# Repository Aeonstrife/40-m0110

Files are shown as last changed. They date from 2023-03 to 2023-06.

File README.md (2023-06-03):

# 40-m0110 PCB
 
An OpenSource 40% PCB compatible with Ani's 40-m0110 case.  
Made for the Indian Mechanical Keyboard Community. 

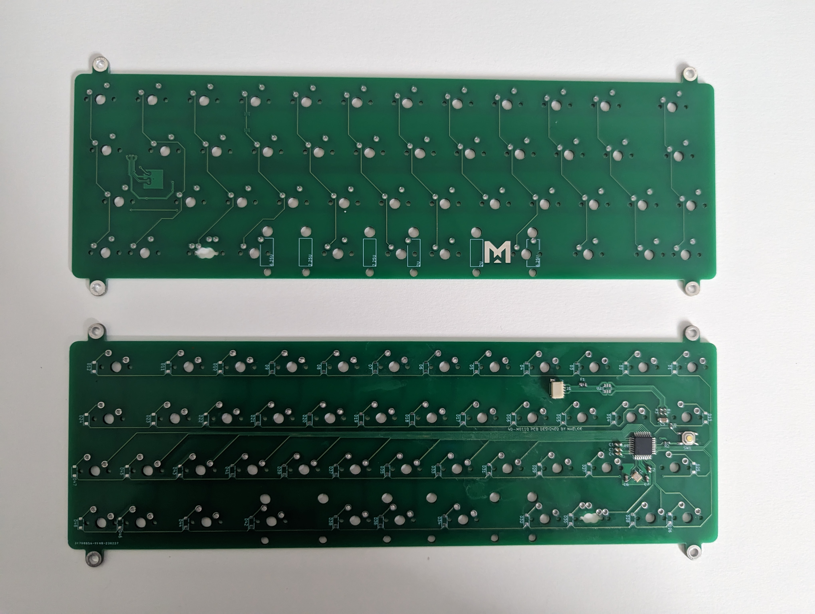
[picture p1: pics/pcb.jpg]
pcb


## Layouts Supported  

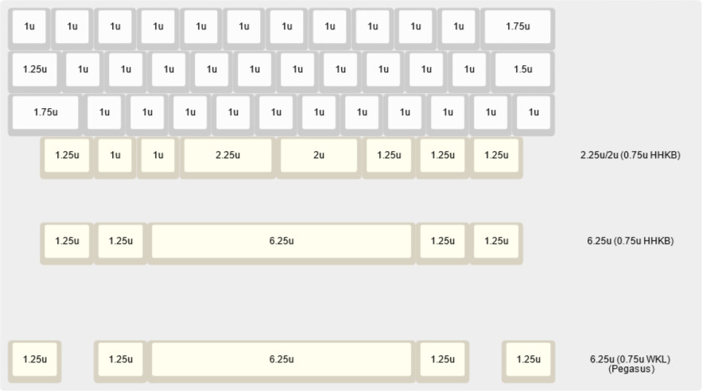
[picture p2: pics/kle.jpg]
layouts supported


## Firmware

### Building the firmware
Copy the folder "40m0110" from the firmware folder to your qmk_firmware/buildakb folder  
Launch QMK MSYS and run: `qmk compile -kb buildakb\40m0110 -km via`  
The firmware file will be created in qmk_firmware/.build folder  

### Flashing the firmware
Launch QMK Toolbox, Select MCU as ATmega32U2, select the firmware file and enable Auto-Flash checkbox.  
Press the reset button on the PCB to put the PCB in Bootloader mode.

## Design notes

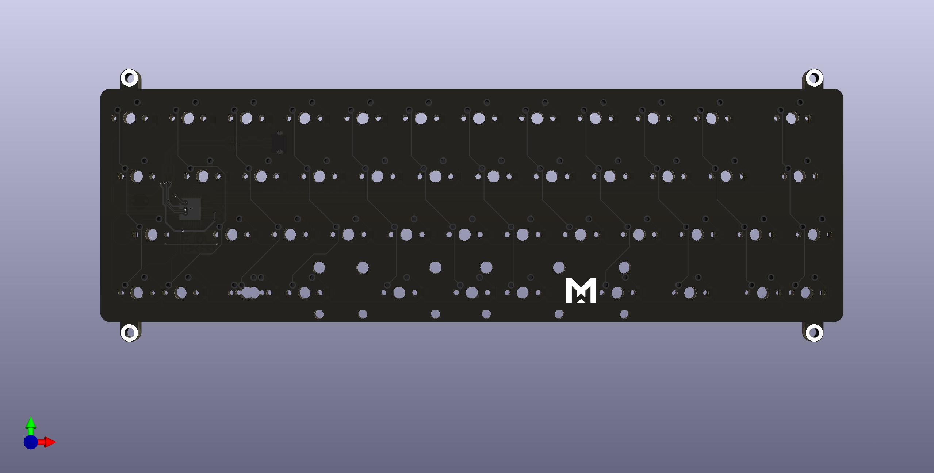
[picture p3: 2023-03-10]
40-m0110.jpg

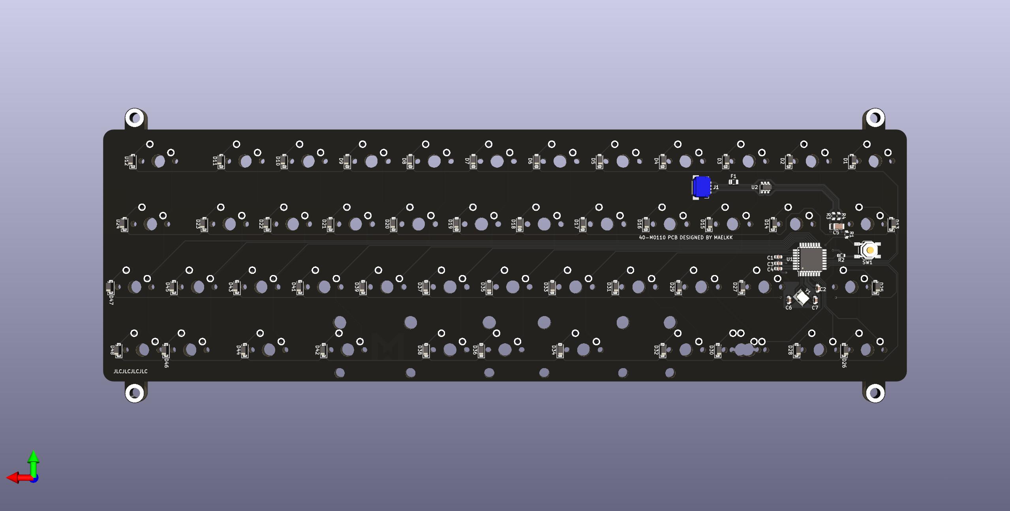
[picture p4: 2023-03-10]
40-m0110_back.jpg

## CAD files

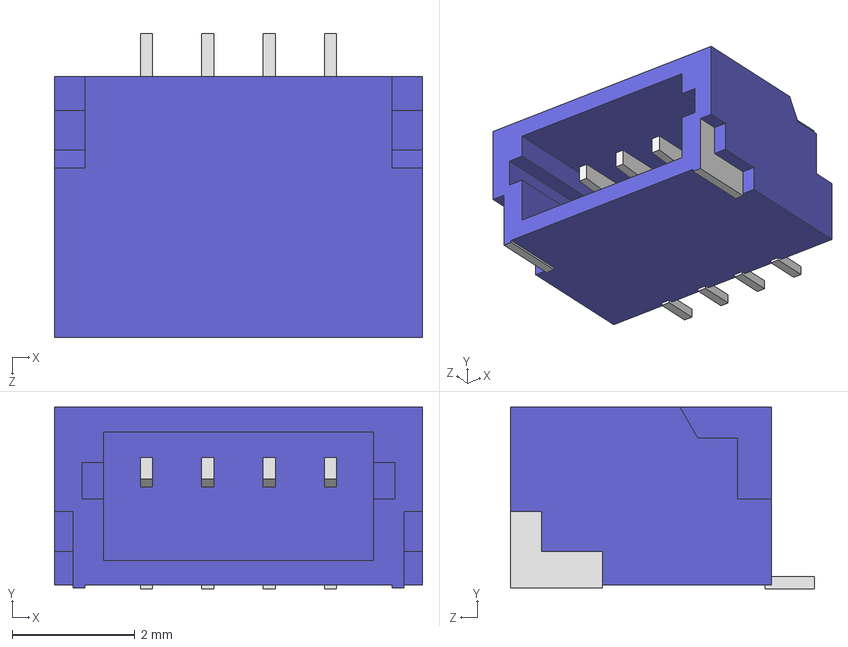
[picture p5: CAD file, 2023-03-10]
SM04B-SRSS-TB.STEP
6.00 x 2.96 x 4.95 mm

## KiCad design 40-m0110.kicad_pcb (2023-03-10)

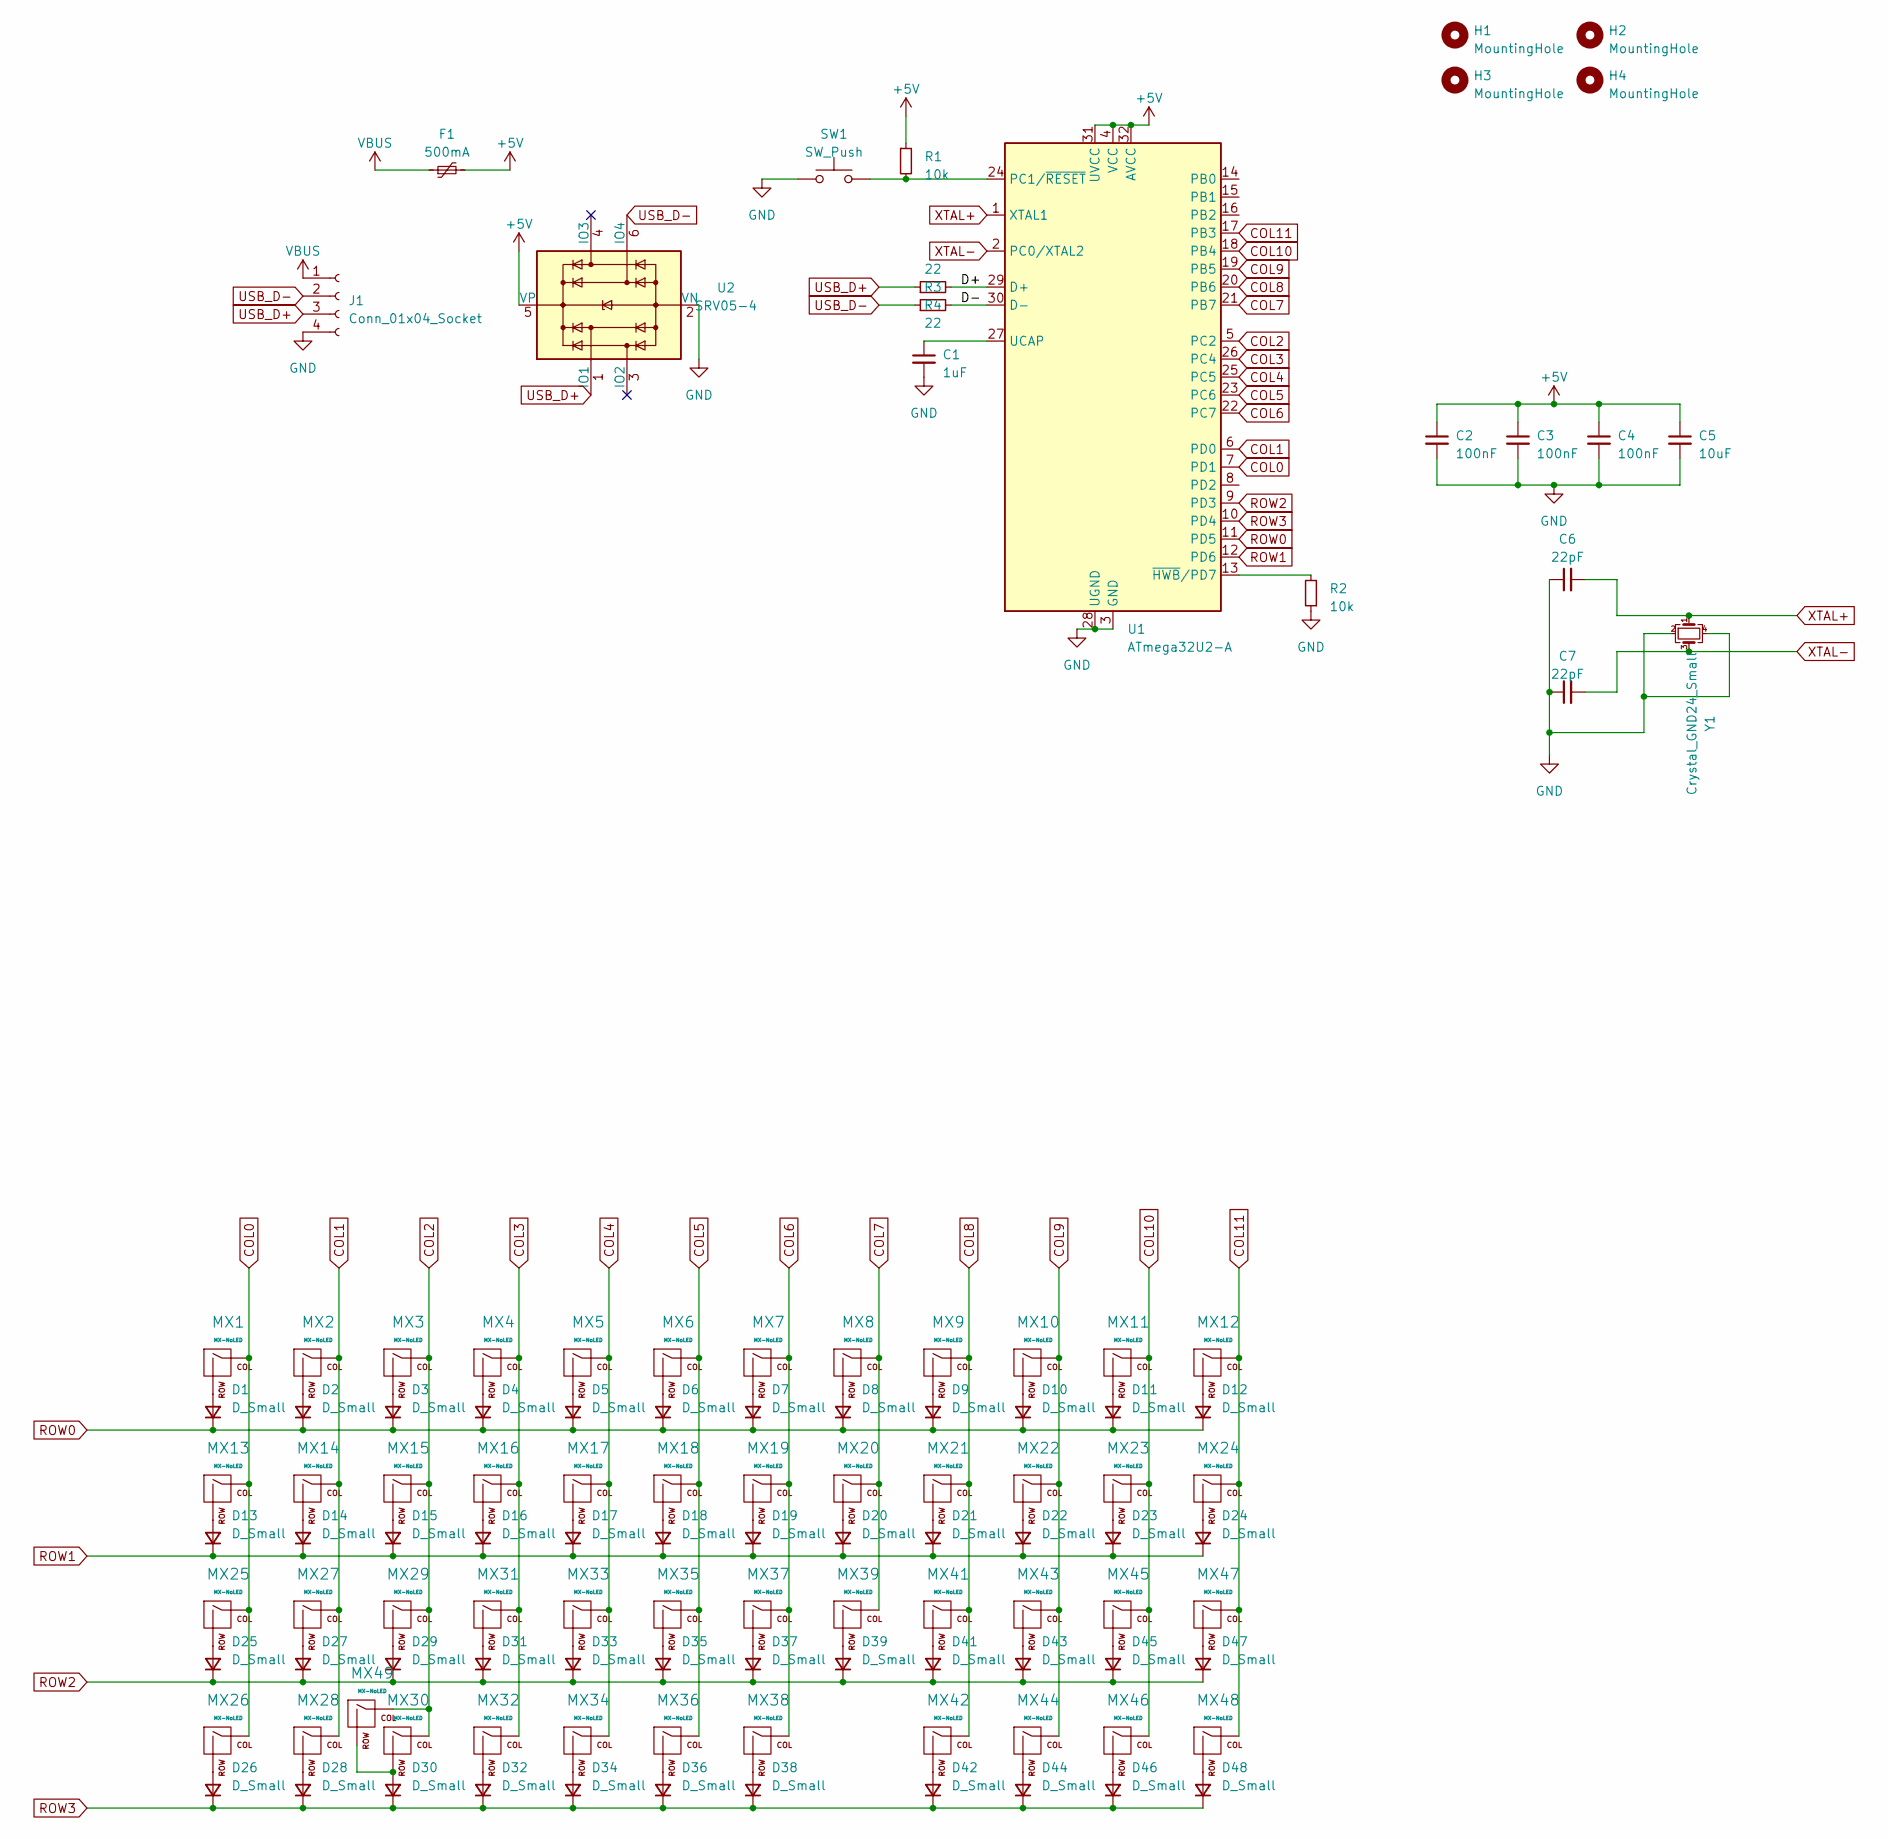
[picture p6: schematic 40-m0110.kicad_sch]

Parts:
C1: 1uF; C_0603_1608Metric
C2, C3, C4: 100nF; C_0603_1608Metric
C5: 10uF; C_0603_1608Metric
C6, C7: 22pF; C_0603_1608Metric
D1, D2, D3, D4, D5, D6, D7, D8, D9, D10, D11, D12, D13, D14, D15, D16, D17, D18, D19, D20, D21, D22, D23, D24, D25, D26, D27, D28, D29, D30, D31, D32, D33, D34, D35, D36, D37, D38, D39, D41, D42, D43, D44, D45, D46, D47, D48: D_Small; D_SOD-123
F1: 500mA; Fuse_0805_2012Metric
H1, H2, H3, H4: MountingHole; MountingHole_3.2mm_M3_DIN965_Pad
J1: Conn_01x04_Socket; SM04B-SRSS-TB(LF)(SN)_mounting-reliefs
MX1, MX2, MX3, MX4, MX5, MX6, MX7, MX8, MX9, MX10, MX11, MX12, MX13, MX14, MX15, MX16, MX17, MX18, MX19, MX20, MX21, MX22, MX23, MX24, MX25, MX26, MX27, MX28, MX29, MX30, MX31, MX32, MX33, MX34, MX35, MX36, MX37, MX38, MX39, MX41, MX42, MX43, MX44, MX45, MX46, MX47, MX48, MX49: MX-NoLED; MXOnly-1U-NoLED
R1, R2: 10k; R_0603_1608Metric
R3, R4: 22; R_0603_1608Metric
SW1: SW_Push; SW_SPST_TL3342
U1: ATmega32U2-A; TQFP-32_7x7mm_P0.8mm
U2: SRV05-4; SOT-23-6
Y1: Crystal_GND24_Small; Crystal_SMD_3225-4Pin_3.2x2.5mm

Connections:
+5V: C2.1, C3.1, C4.1, C5.1, F1.2, R1.1, U1.4 (VCC), U1.31 (UVCC), U1.32 (AVCC), U2.5 (VP)
/D+: R3.2, U1.29 (D+)
/D-: R4.2, U1.30 (D-)
COL0: MX1.1 (COL), MX13.1 (COL), MX25.1 (COL), MX26.1 (COL), U1.7 (PD1)
COL1: MX2.1 (COL), MX14.1 (COL), MX27.1 (COL), MX28.1 (COL), U1.6 (PD0)
COL2: MX3.1 (COL), MX15.1 (COL), MX29.1 (COL), MX30.1 (COL), MX49.1 (COL), U1.5 (PC2)
COL3: MX4.1 (COL), MX16.1 (COL), MX31.1 (COL), MX32.1 (COL), U1.26 (PC4)
COL4: MX5.1 (COL), MX17.1 (COL), MX33.1 (COL), MX34.1 (COL), U1.25 (PC5)
COL5: MX6.1 (COL), MX18.1 (COL), MX35.1 (COL), MX36.1 (COL), U1.23 (PC6)
COL6: MX7.1 (COL), MX19.1 (COL), MX37.1 (COL), MX38.1 (COL), U1.22 (PC7)
COL7: MX8.1 (COL), MX20.1 (COL), MX39.1 (COL), U1.21 (PB7)
COL8: MX9.1 (COL), MX21.1 (COL), MX41.1 (COL), MX42.1 (COL), U1.20 (PB6)
COL9: MX10.1 (COL), MX22.1 (COL), MX43.1 (COL), MX44.1 (COL), U1.19 (PB5)
COL10: MX11.1 (COL), MX23.1 (COL), MX45.1 (COL), MX46.1 (COL), U1.18 (PB4)
COL11: MX12.1 (COL), MX24.1 (COL), MX47.1 (COL), MX48.1 (COL), U1.17 (PB3)
GND: C1.2, C2.2, C3.2, C4.2, C5.2, C6.1, C7.1, J1.4, R2.1, SW1.1, U1.3 (GND), U1.28 (UGND), U2.2 (VN), Y1.2, Y1.4
unnamed: D1.2 (A), MX1.2 (ROW)
unnamed: D2.2 (A), MX2.2 (ROW)
unnamed: D3.2 (A), MX3.2 (ROW)
unnamed: D4.2 (A), MX4.2 (ROW)
unnamed: D5.2 (A), MX5.2 (ROW)
unnamed: D6.2 (A), MX6.2 (ROW)
unnamed: D7.2 (A), MX7.2 (ROW)
unnamed: D8.2 (A), MX8.2 (ROW)
unnamed: D9.2 (A), MX9.2 (ROW)
unnamed: D10.2 (A), MX10.2 (ROW)
unnamed: D11.2 (A), MX11.2 (ROW)
unnamed: D12.2 (A), MX12.2 (ROW)
unnamed: D13.2 (A), MX13.2 (ROW)
unnamed: D14.2 (A), MX14.2 (ROW)
unnamed: D15.2 (A), MX15.2 (ROW)
unnamed: D16.2 (A), MX16.2 (ROW)
unnamed: D17.2 (A), MX17.2 (ROW)
unnamed: D18.2 (A), MX18.2 (ROW)
unnamed: D19.2 (A), MX19.2 (ROW)
unnamed: D20.2 (A), MX20.2 (ROW)
unnamed: D21.2 (A), MX21.2 (ROW)
unnamed: D22.2 (A), MX22.2 (ROW)
unnamed: D23.2 (A), MX23.2 (ROW)
unnamed: D24.2 (A), MX24.2 (ROW)
unnamed: D25.2 (A), MX25.2 (ROW)
unnamed: D26.2 (A), MX26.2 (ROW)
unnamed: D27.2 (A), MX27.2 (ROW)
unnamed: D28.2 (A), MX28.2 (ROW)
unnamed: D29.2 (A), MX29.2 (ROW)
unnamed: D30.2 (A), MX30.2 (ROW), MX49.2 (ROW)
unnamed: D31.2 (A), MX31.2 (ROW)
unnamed: D32.2 (A), MX32.2 (ROW)
unnamed: D33.2 (A), MX33.2 (ROW)
unnamed: D34.2 (A), MX34.2 (ROW)
unnamed: D35.2 (A), MX35.2 (ROW)
unnamed: D36.2 (A), MX36.2 (ROW)
unnamed: D37.2 (A), MX37.2 (ROW)
unnamed: D38.2 (A), MX38.2 (ROW)
unnamed: D39.2 (A), MX39.2 (ROW)
unnamed: D41.2 (A), MX41.2 (ROW)
unnamed: D42.2 (A), MX42.2 (ROW)
unnamed: D43.2 (A), MX43.2 (ROW)
unnamed: D44.2 (A), MX44.2 (ROW)
unnamed: D45.2 (A), MX45.2 (ROW)
unnamed: D46.2 (A), MX46.2 (ROW)
unnamed: D47.2 (A), MX47.2 (ROW)
unnamed: D48.2 (A), MX48.2 (ROW)
unnamed: R1.2, SW1.2, U1.24 (PC1/~RESET)
unnamed: C1.1, U1.27 (UCAP)
unnamed: R2.2, U1.13 (~HWB/PD7)
ROW0: D1.1 (K), D2.1 (K), D3.1 (K), D4.1 (K), D5.1 (K), D6.1 (K), D7.1 (K), D8.1 (K), D9.1 (K), D10.1 (K), D11.1 (K), D12.1 (K), U1.11 (PD5)
ROW1: D13.1 (K), D14.1 (K), D15.1 (K), D16.1 (K), D17.1 (K), D18.1 (K), D19.1 (K), D20.1 (K), D21.1 (K), D22.1 (K), D23.1 (K), D24.1 (K), U1.12 (PD6)
ROW2: D25.1 (K), D27.1 (K), D29.1 (K), D31.1 (K), D33.1 (K), D35.1 (K), D37.1 (K), D39.1 (K), D41.1 (K), D43.1 (K), D45.1 (K), D47.1 (K), U1.9 (PD3)
ROW3: D26.1 (K), D28.1 (K), D30.1 (K), D32.1 (K), D34.1 (K), D36.1 (K), D38.1 (K), D42.1 (K), D44.1 (K), D46.1 (K), D48.1 (K), U1.10 (PD4)
USB_D+: J1.3, R3.1, U2.1 (IO1)
USB_D-: J1.2, R4.1, U2.6 (IO4)
VBUS: F1.1, J1.1
XTAL+: C6.2, U1.1 (XTAL1), Y1.1
XTAL-: C7.2, U1.2 (PC0/XTAL2), Y1.3

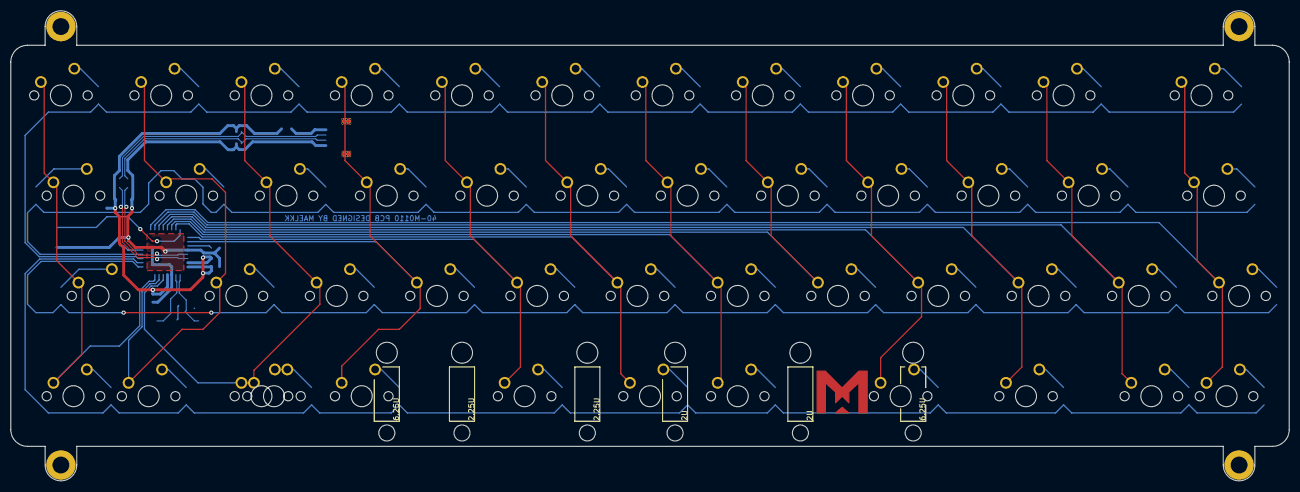
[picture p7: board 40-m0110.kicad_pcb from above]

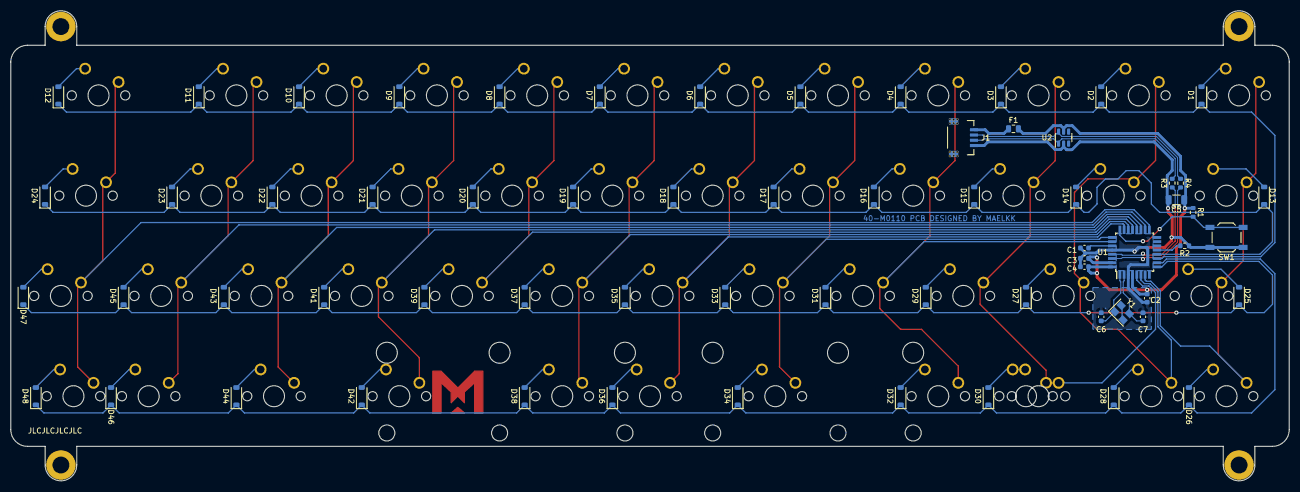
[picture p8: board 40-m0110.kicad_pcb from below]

Board: 2 copper layers, 242.9 x 89.3 mm, 116 parts (64 on the bottom side), 75 nets.
